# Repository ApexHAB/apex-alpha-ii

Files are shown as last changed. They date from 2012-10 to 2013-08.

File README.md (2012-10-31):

# Apex Alpha II
## A tiny, light-weight 'pico' flight computer with potential applications as a balloon neck payload

The flight computer is based around a CC430 microcontroller and radio by Texas Instruments with a uBlox Max-6.
It runs off a single AAA battery.

## Useful links

* [Homepage](http://www.apexhab.org) - http://www.apexhab.org
* [Apex Alpha II Homepage](http://www.apexhab.org/alpha-ii/) - http://www.apexhab.org/alpha-ii/
* [Contact](mailto:team@apexhab.org) - team@apexhab.org
* [Twitter](http://twitter.com/apexhab) - http://twitter.com/apexhab

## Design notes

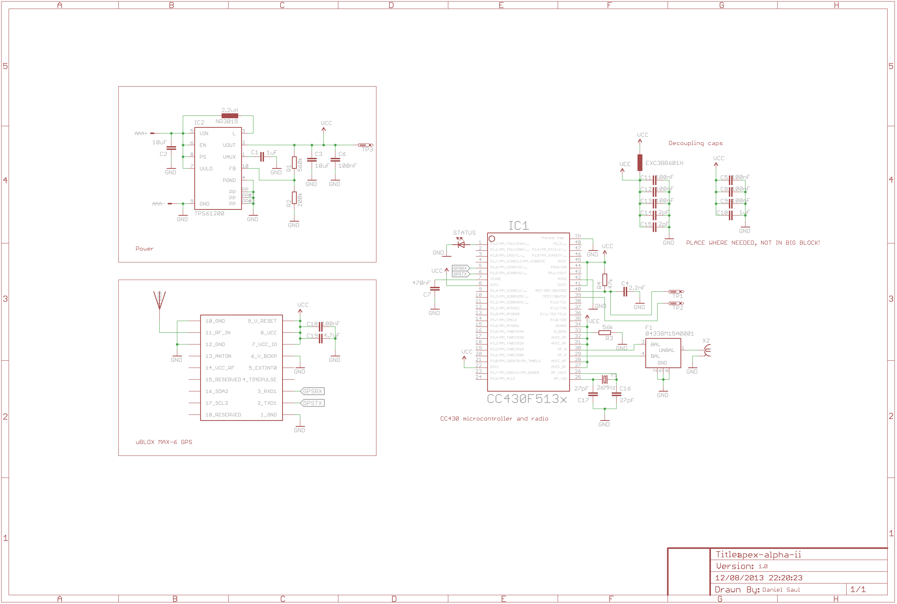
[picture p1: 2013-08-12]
PCB/schematic.png

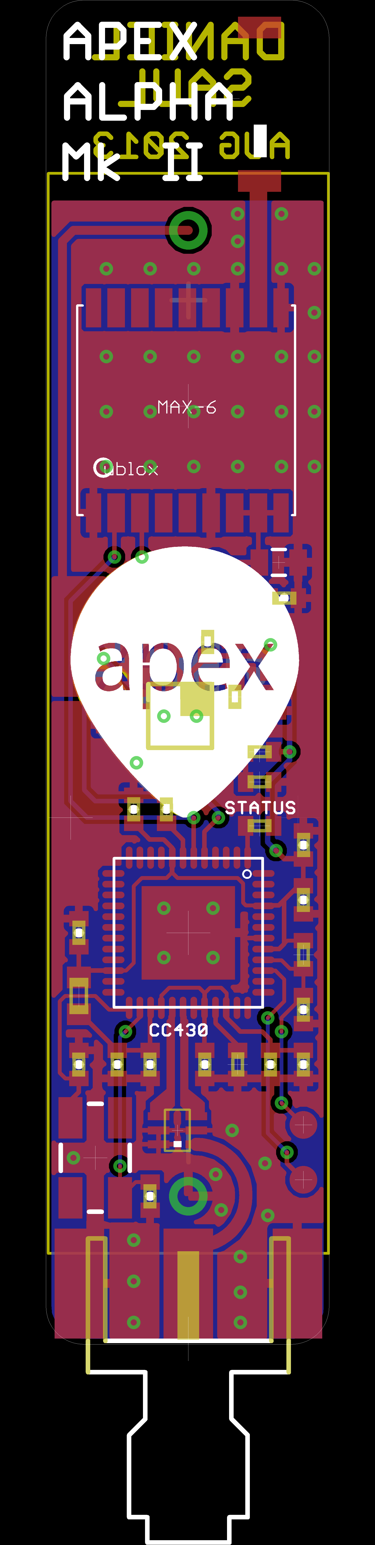
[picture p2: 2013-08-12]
PCB/pcb.png

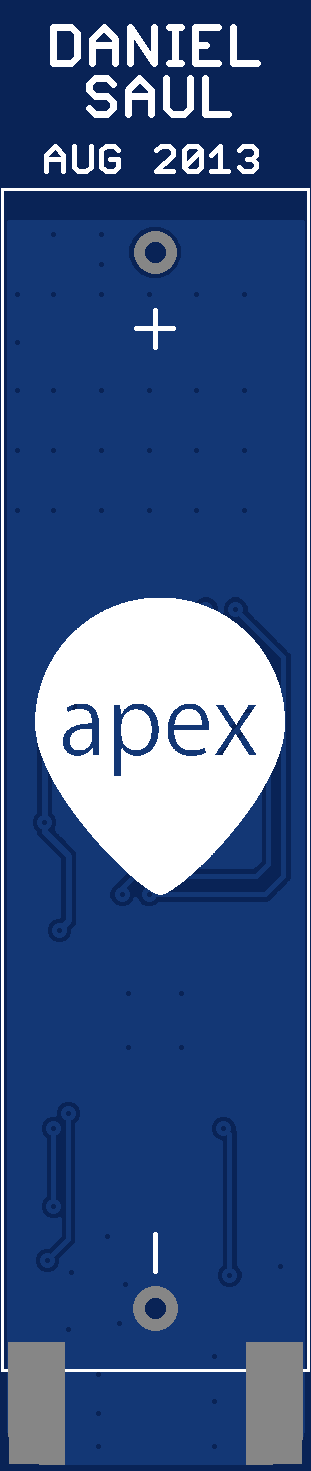
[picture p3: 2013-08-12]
PCB/board_bottom.png

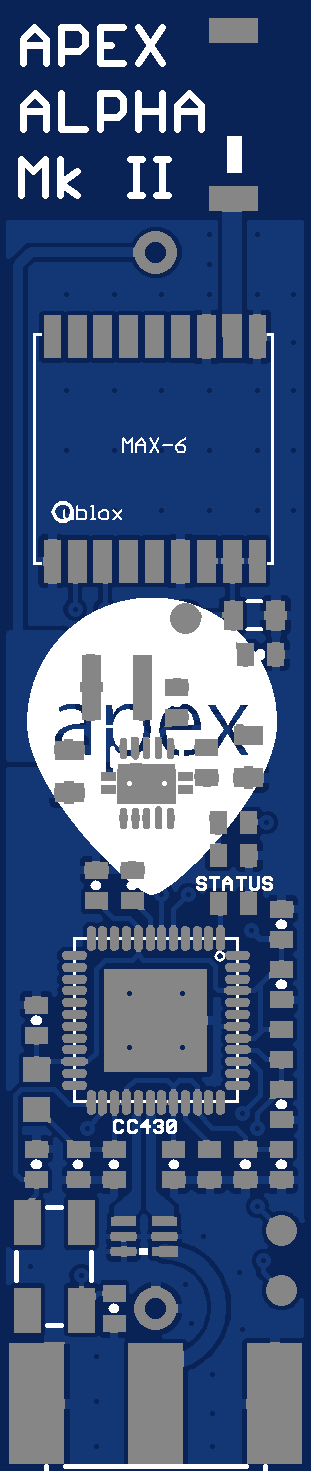
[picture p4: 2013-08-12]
PCB/board_top.png

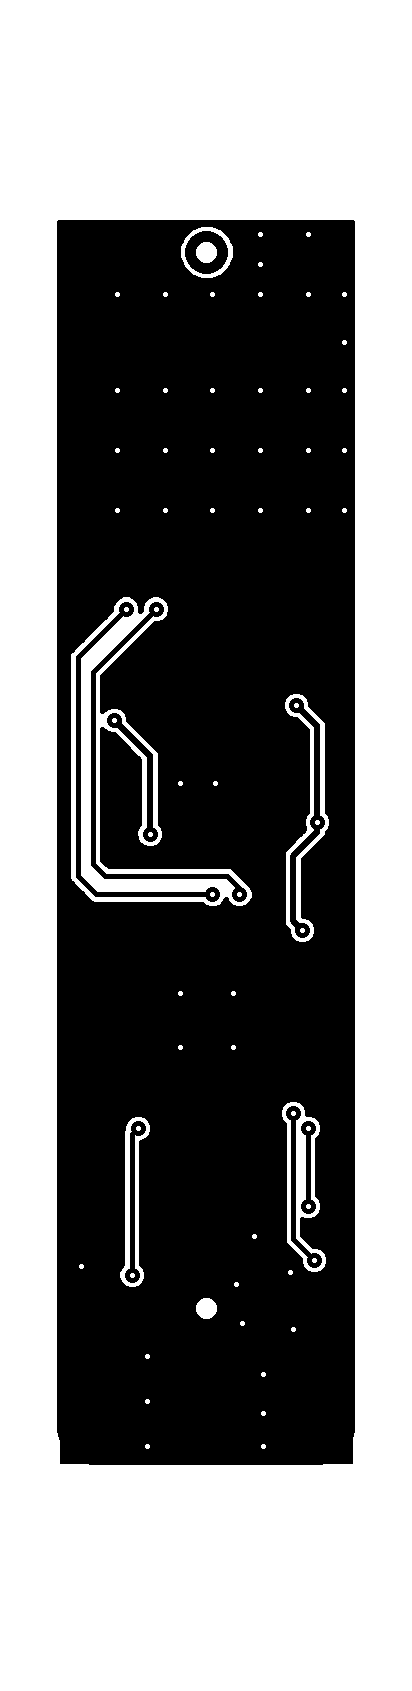
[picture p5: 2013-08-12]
PCB/copper_bottom.png

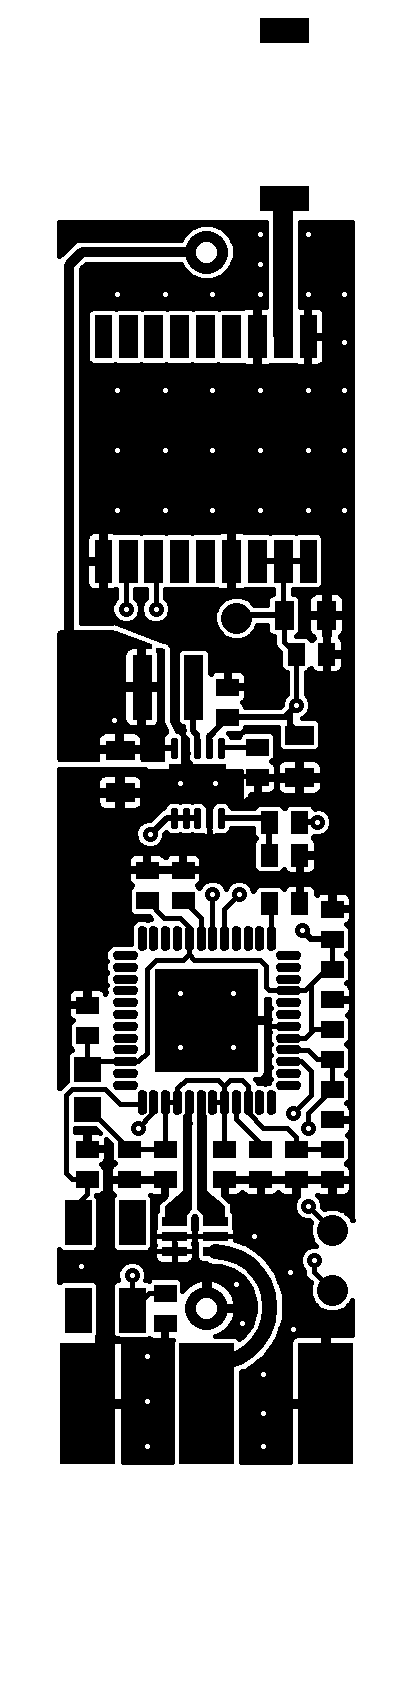
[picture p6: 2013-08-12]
PCB/copper_top.png

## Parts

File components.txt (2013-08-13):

Farnell
============
26MHz crystal	 			1841998 or 1841997
Red 0805 1.85V LED  			1318244
Power Inductor NR3015 2.2uH  		1612110
Inductor EXC3BB601H  			1292697
Keystone AAA Battery Holder 2466  	1702632

433MHz Balun 0433BM15A0001 		2148531

10uF 0805 Capacitor (x2)		1828828
4.7uF 0805 Capacitor			1845769

1uF 0402 Capacitor (x2)			1288253		
100nF 0402 Capacitor (x8)		1288252
470nF 0402 Capacitor			8819726
2.2nF 0402 Capacitor			1414582
27pF 0402 Capacitor (x2)		1414584
2pF 0402 Capacitor (x2)			8771340

560k 0402 Resistor			2141009
200k 0402 Resistor			1469694
56k 0402 Resistor			2073131
47k 0402 Resistor			2073065

HAB Supplies
===========
uBlox MAX-6G (1.8V)
GPS Chip Antenna

Free Samples
===========
TI TPS61200
TI CC430F513x

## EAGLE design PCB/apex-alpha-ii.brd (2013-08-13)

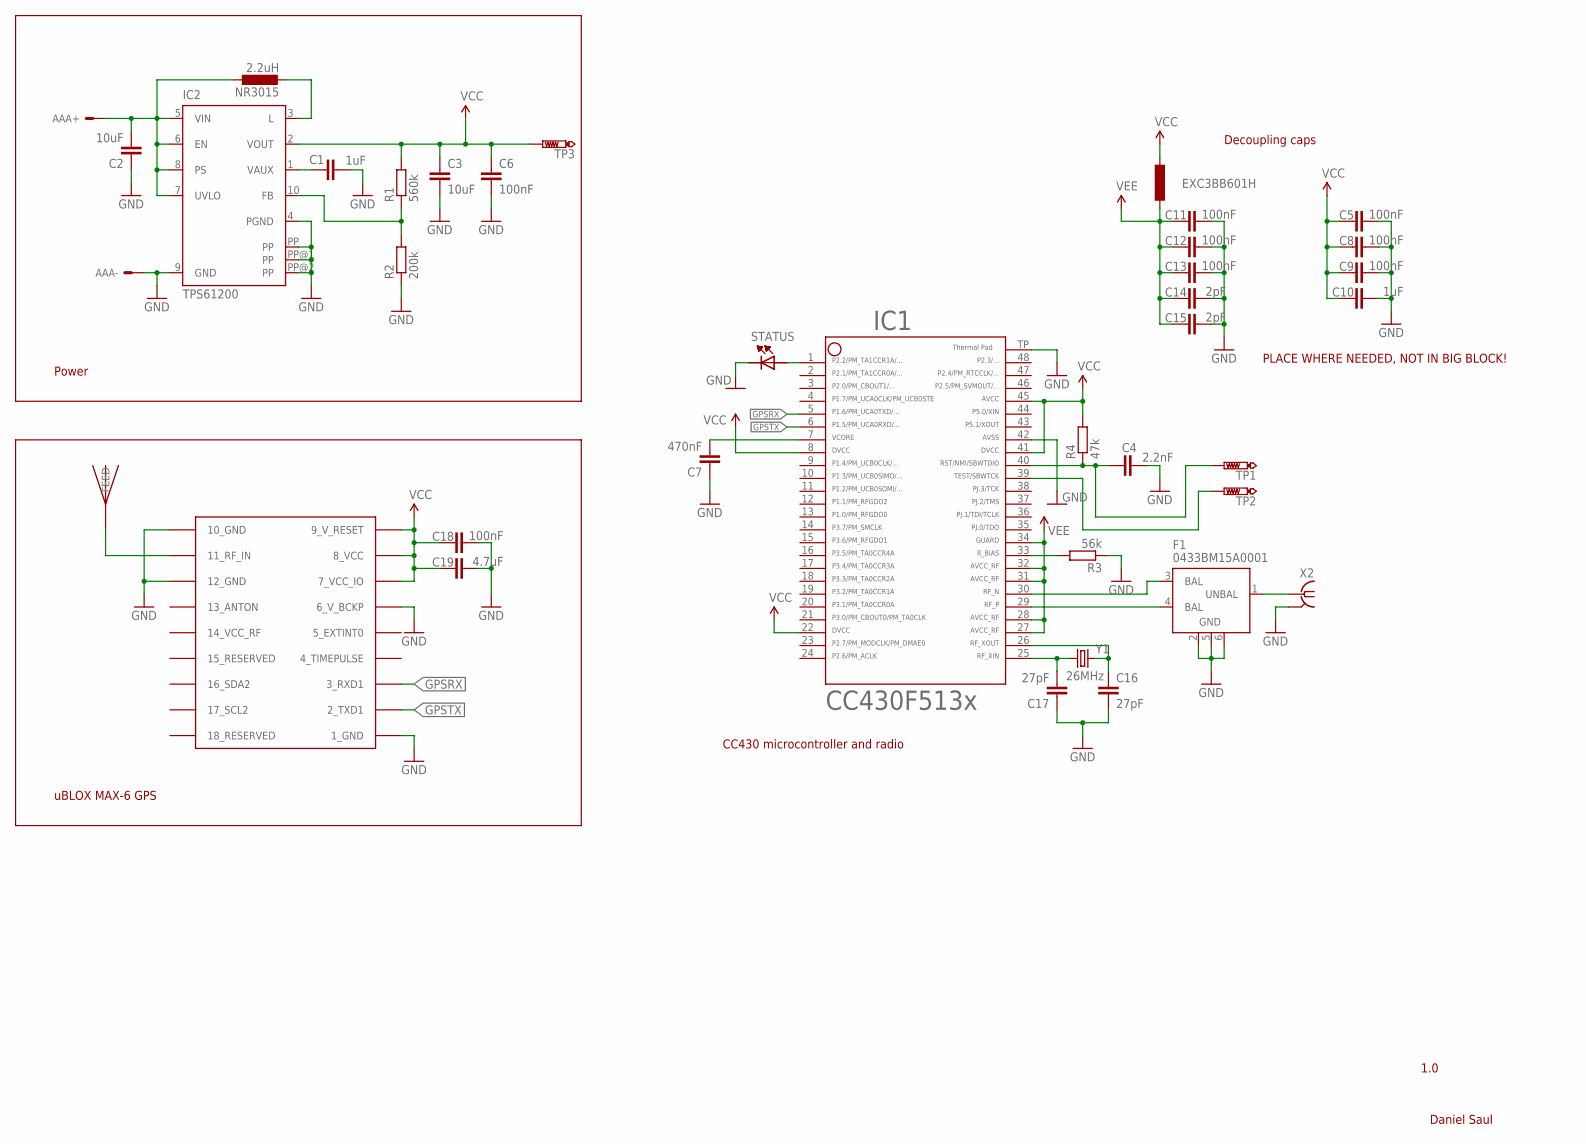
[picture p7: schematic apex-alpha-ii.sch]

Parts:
AAA: KEYSTONE-2466-THROUGH-HOLE-BATTERY-HOLDER-AAA; THROUGH-HOLE-BATTERY-HOLDER-AAA
C1, C10: 1uF; 0402-CAP
C2, C3: 10uF; 0805
C4: 2.2nF; 0402-CAP
C5, C6, C8, C9, C11, C12, C13, C18: 100nF; 0402-CAP
C7: 470nF; 0402-CAP
C14, C15: 2pF; 0402-CAP
C16, C17: 27pF; 0402-CAP
C19: 4.7uF; 0805
F1: 0433BM15A0001; 2450BM15A0002
GPS: UBLOX_MAX-6
IC1: CC430F5135; RGZ48
IC2: TPS61200; S-PDSO-N10
NR3015: 2.2uH; NR3015
R1: 560k; R0402
R2: 200k; R0402
R3: 56k; R0402
R4: 47k; R0402
TP1, TP2, TP3: PTR1B1,27; B1,27
U$1: JTI_ANTENNA-1575AT43A40
U$2: EXC3BB601H; R0603
U$3: STATUS; R0402
X2: SMA-142-0701-801/806; J502-ND-142-0701-801/806; MPN 142-0701-801
Y1: 26MHz; CRYSTAL-SMD-5X3

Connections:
GND: AAA.GND, C1.2, C2.1, C3.2, C4.2, C5.2, C6.2, C7.1, C8.2, C9.2, C10.2, C11.2, C12.2, C13.2, C14.2, C15.2, C16.2, C17.1, C18.2, C19.2, F1.2 (GND), F1.5 (GND), F1.6 (GND), GPS.1_GND, GPS.6_V_BCKP, GPS.10_GND, GPS.12_GND, IC1.42, IC1.TP (49), IC2.4 (PGND), IC2.9 (GND), IC2.PP, IC2.PP@1 (PP), IC2.PP@2 (PP), R2.1, R3.1, U$3.1 (C), X2.G@1 (GND), X2.G@2 (GND), X2.G@3 (GND), X2.G@4 (GND)
GPSRX: GPS.3_RXD1, IC1.5
GPSTX: GPS.2_TXD1, IC1.6
unnamed: AAA.+V, C2.2, IC2.5 (VIN), IC2.6 (EN), IC2.7 (UVLO), IC2.8 (PS), NR3015.P$1 (1)
unnamed: F1.3 (BAL), IC1.30
unnamed: IC2.3 (L), NR3015.P$2 (2)
unnamed: IC2.10 (FB), R1.1, R2.2
unnamed: C1.1, IC2.1 (VAUX)
unnamed: F1.4 (BAL), IC1.29
unnamed: F1.1 (UNBAL), X2.1
unnamed: GPS.11_RF_IN, U$1.FEED
unnamed: IC1.33, R3.2
unnamed: C7.2, IC1.7
unnamed: C4.1, IC1.40, R4.1, TP1.TP
unnamed: IC1.39, TP2.TP
unnamed: C17.2, IC1.25, Y1.1
unnamed: C16.1, IC1.26, Y1.3 (2)
unnamed: IC1.1, U$3.2 (A)
VCC: C3.1, C5.1, C6.1, C8.1, C9.1, C10.1, C18.1, C19.1, GPS.7_VCC_IO, GPS.8_VCC, GPS.9_V_RESET, IC1.8, IC1.22, IC1.41, IC1.45, IC2.2 (VOUT), R1.2, R4.2, TP3.TP, U$2.1
VEE: C11.1, C12.1, C13.1, C14.1, C15.1, IC1.27, IC1.28, IC1.31, IC1.32, IC1.34, U$2.2

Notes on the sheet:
1.0
Daniel Saul
Decoupling caps
Power
uBLOX MAX-6 GPS
CC430 microcontroller and radio
PLACE WHERE NEEDED, NOT IN BIG BLOCK!

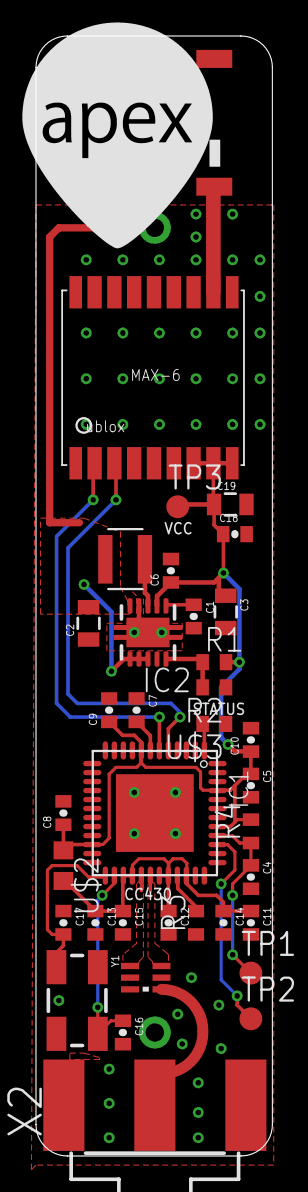
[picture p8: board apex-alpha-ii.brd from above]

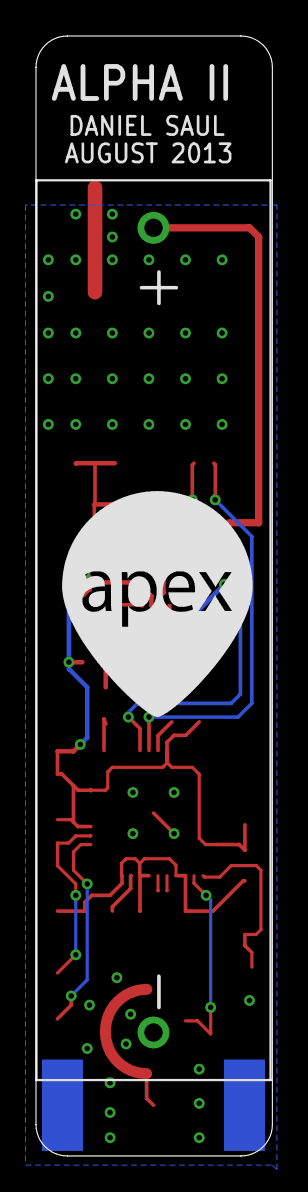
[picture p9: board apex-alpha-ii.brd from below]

Board: 2 copper layers, 13.1 x 62.2 mm, 39 parts (2 on the bottom side), 20 nets.

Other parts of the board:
U$4: APEX; APEXHAB-LOGO-SMALL
U$5: APEXHAB-LOGO-SMALL

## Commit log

2012-10-31 Schematic complete
    [apex-alpha-ii.sch]
2012-12-27 Started board - battery positive under ublox, negative under radio
    [apex-alpha-ii.brd]
2012-12-27 Flipped battery - still AAA
    [apex-alpha-ii.brd, apex-alpha-ii.sch]
2012-12-27 Changed to TLV70019 linear reg for a 3V battery
    [apex-alpha-ii-aaa-version.brd, apex-alpha-ii-aaa-version.sch]
2012-12-27 Replaced AAA holder with CR123A holder
    [apex-alpha-ii.brd, apex-alpha-ii.sch]
2012-12-27 Renamed to CR123a version
    [apex-alpha-ii-cr123a-version.brd, apex-alpha-ii-cr123a-version.sch]
2012-12-27 AAA version fully laid out.
    [apex-alpha-ii-aaa-version.brd, apex-alpha-ii-aaa-version.sch]
2012-12-28 Ground planes. Started routing.
    [apex-alpha-ii-aaa-version.brd, apex-alpha-ii-aaa-version.sch]
2012-12-29 Nearly finished routing... committing before I lose it all.
    [apex-alpha-ii-aaa-version.brd, apex-alpha-ii-aaa-version.sch]
2012-12-29 Finished! I think.
    [apex-alpha-ii-aaa-version.brd, apex-alpha-ii-aaa-version.sch]
2012-12-29 Added huge image of board
2013-08-08 New PCB layout etc.
    [apex-alpha-ii-aaa-version-old.brd, apex-alpha-ii-aaa-version.brd, apex-alpha-ii-aaa-version.sch]
2013-08-12 Final PCB layout
    [apex-alpha-ii-aaa-version-old.brd, apex-alpha-ii-aaa-version.brd, apex-alpha-ii-cr123a-version.sch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]
2013-08-13 Generated gerbers
    [apex-alpha-ii.brd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]
2013-08-13 Removed component names from silkscreen
    [apex-alpha-ii.GTO]

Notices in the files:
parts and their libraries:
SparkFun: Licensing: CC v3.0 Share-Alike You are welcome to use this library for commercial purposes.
